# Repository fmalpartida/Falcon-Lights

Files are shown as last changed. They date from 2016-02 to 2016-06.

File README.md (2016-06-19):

# Falcon-Lights
Bandai 1:144 Millenium Falcon Light kit driver. 

This is a small board that retorfits into LED light compartment of the Bandai 1:144 Millenium Falcon kit.

The main difference between the original kit is its capability of driving upto to 6 white LEDs running from 2 AAAA batteries and fitting the whole assembly into the original compartment inside the Falcon.

## 3D Renders
Top

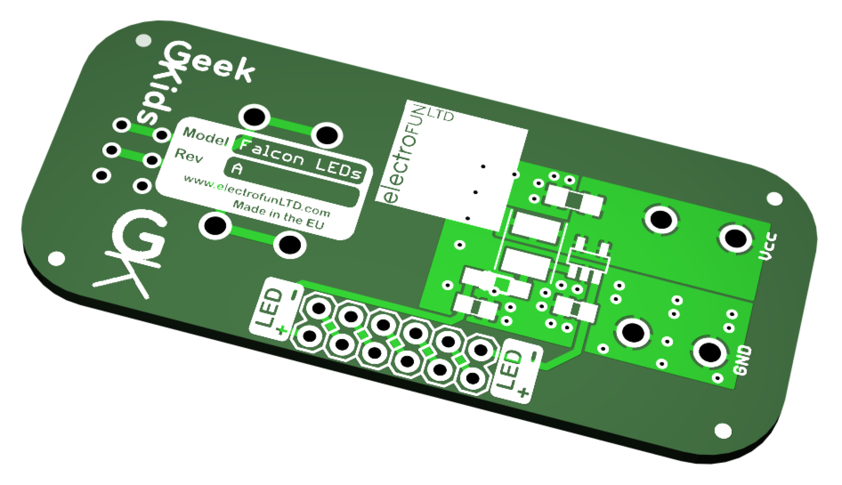
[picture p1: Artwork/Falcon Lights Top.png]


Bottom

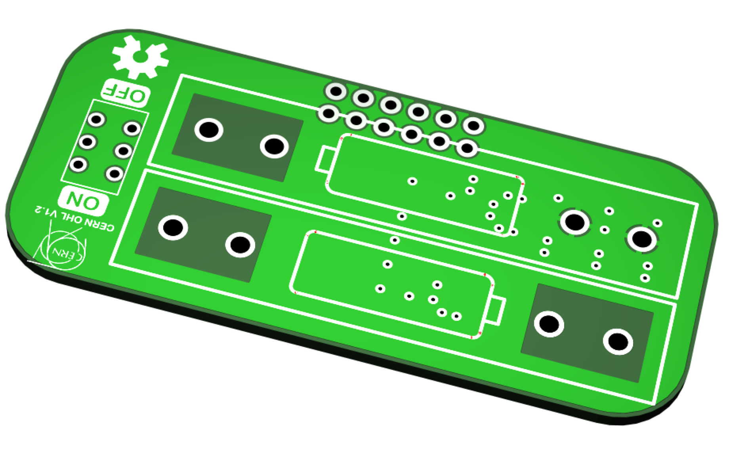
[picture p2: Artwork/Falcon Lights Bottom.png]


## Geek Kids Project
The board has been developed by electronFUN under the Geek Kids initiative. 

The Geek Kids initiative is a local electroFUN project where we try to bring youngsters close to technology. Kids under the initiative get exposed to technology projects while participating in them and bring up to speed for sharing with the general public. 

All the benefits derived from Geek Kids projects will revert back to the initiative and will help them develop more stuff and reachout to more kids.

All these projects are released under the Geek Kids logo and are Open Source for everyone to enjoy. 



Stay tunned.

## Where to get them
We don't have intentions to sell them and encourrage you to build them by yourself. If you would like us to build one for you please let me know by sending me a message, we will be delighted to build one for you.

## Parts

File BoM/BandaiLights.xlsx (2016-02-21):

Qty | Value | Device | Package | Parts | Description | Ref | Unit Price | TOTAL
6 |  | M02PTH | 1X02 | LED1, LED2, LED3, LED4, LED5, LED6 | Header 2 + LEDs |  | 0.0264 | 0.1584
1 | 1uF | C-EUC0805 | C0805 | C3 | CAPACITOR, European symbol | CC0805ZKY5V9BB105 | 0.053 | 0.053
1 | 10uF | C-EUC1206 | C1206 | C2 | CAPACITOR, European symbol | C1206C106Z8VACTU | 0.073 | 0.073
1 | 10uH-SRN3015-100M | WE-TPC_S | WE-TPC_S | L1 | Shielded Tiny Power Inductor WE-TPC | SRN3015-100M | 0.246 | 0.246
1 | 15R | R-EU_M0805 | M0805 | R1 | RESISTOR, European symbol | 667-ERJ-6ENF15R0V | 0.026 | 0.026
4 | AAAA-BATTERY | AAAA-BATTERY | 51-AAAA | U1, U2 |  | 534-51 | 0.238 | 0.952
1 | MBR0530L-TP | MBR0530LT | SOD123 | D1 | SCHOTTKY BARRIER RECTIFIER | MBR0530L-TP | 0.198 | 0.198
1 | FAN5333B | CAT4238 | SOT23-5 | Q1 | CAT4238 High efficiency 10 LED boost converter- ON Semi. | FAN5333B | 0.743 | 0.743
1 | JS202011CQN | MINI_SWITCH | SWITCH-JS202011 | S1 | Mini Switch ON-MON-OFF | JS202011CQN | 0.317 | 0.317
1 | PCB | FALCON LEDs |  |  | PCB fabrication |  | 4 | 4
6 | JST connectors |  |  |  |  |  | 0.4 | 2.4
 |  |  |  |  |  | TOTAL 10 u |  | 9.1664
 |  |  |  |  |  | VAT | 0.21 | 11.09

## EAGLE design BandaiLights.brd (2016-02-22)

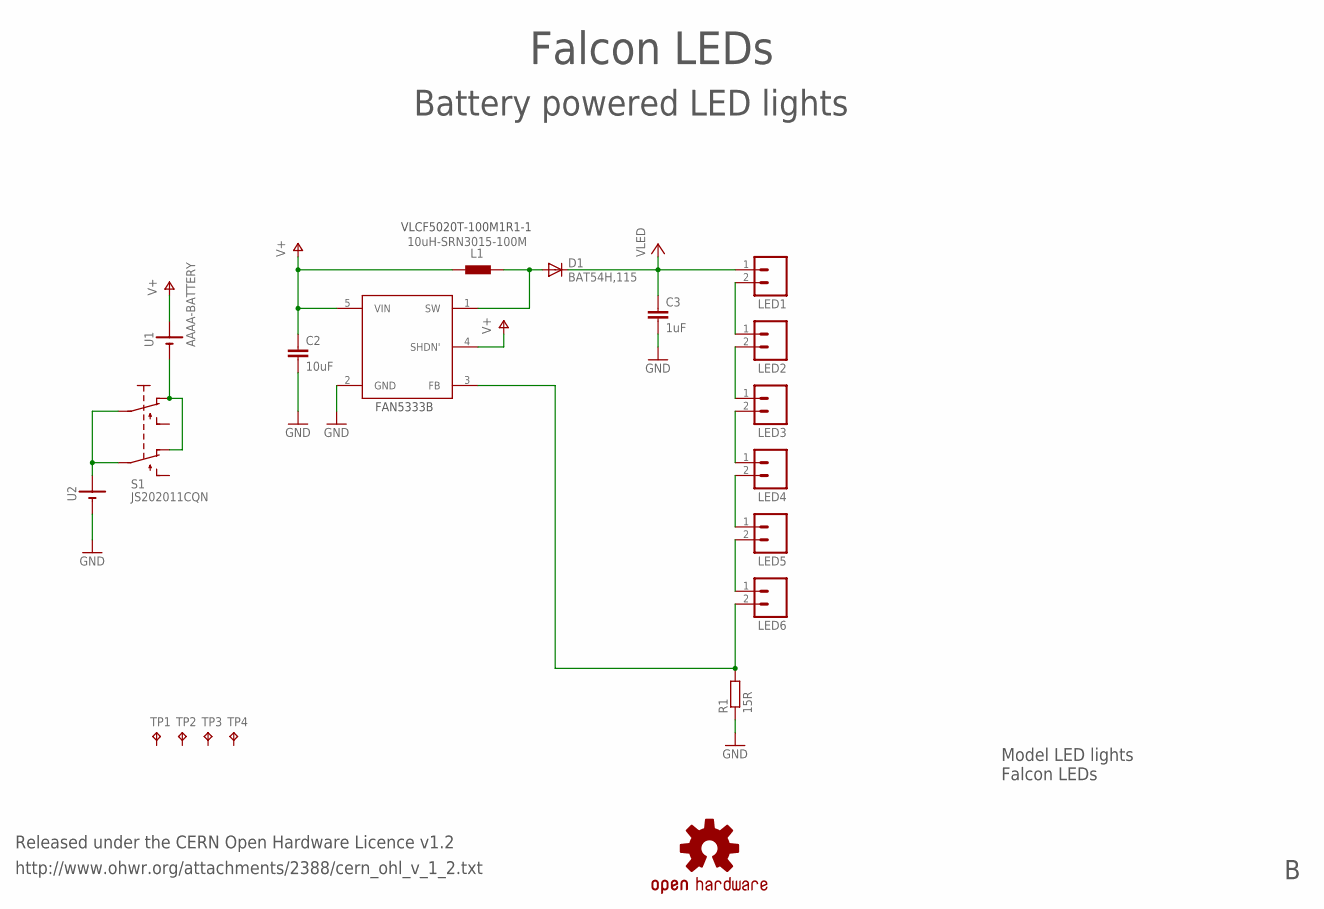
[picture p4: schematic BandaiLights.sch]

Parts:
C2: 10uF; C1206
C3: 1uF; C0805
D1: BAT54H,115; SOD123
L1: 10uH-SRN3015-100M; LQH
LED1, LED2, LED3, LED4, LED5, LED6: M02PTH; 1X02
Q1: FAN5333B; SOT23-5
R1: 15R; M0805
S1: JS202011CQN; SWITCH-JS202011
TP1, TP2, TP3, TP4: TPB1,27; B1,27
U1, U2: AAAA-BATTERY; 51-AAAA
U$4: SPARKFUN_OSHW-LOGOM; SPARKFUN_OSHW-LOGO-M

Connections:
FB: LED6.2, Q1.3 (FB), R1.2
GND: C2.2, C3.2, Q1.2 (GND), R1.1, U2.P3 (-), U2.P4 (-)
unnamed: LED1.2, LED2.1
unnamed: LED2.2, LED3.1
unnamed: LED3.2, LED4.1
unnamed: LED4.2, LED5.1
unnamed: D1.A, L1.2, Q1.1 (SW)
unnamed: LED5.2, LED6.1
unnamed: S1.P2, S1.P5 (P1), U2.P1 (+), U2.P2 (+)
unnamed: S1.P1 (O), S1.P4 (O1), U1.P3 (-), U1.P4 (-)
V+: C2.1, L1.1, Q1.4 (SHDN'), Q1.5 (VIN), U1.P1 (+), U1.P2 (+)
VCC: C3.1, D1.C, LED1.1

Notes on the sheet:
FAN5333B
Model LED lights Falcon LEDs
Battery powered LED lights
Released under the CERN Open Hardware Licence v1.2
http://www.ohwr.org/attachments/2388/cern_ohl_v_1_2.txt
VLCF5020T-100M1R1-1
Falcon LEDs

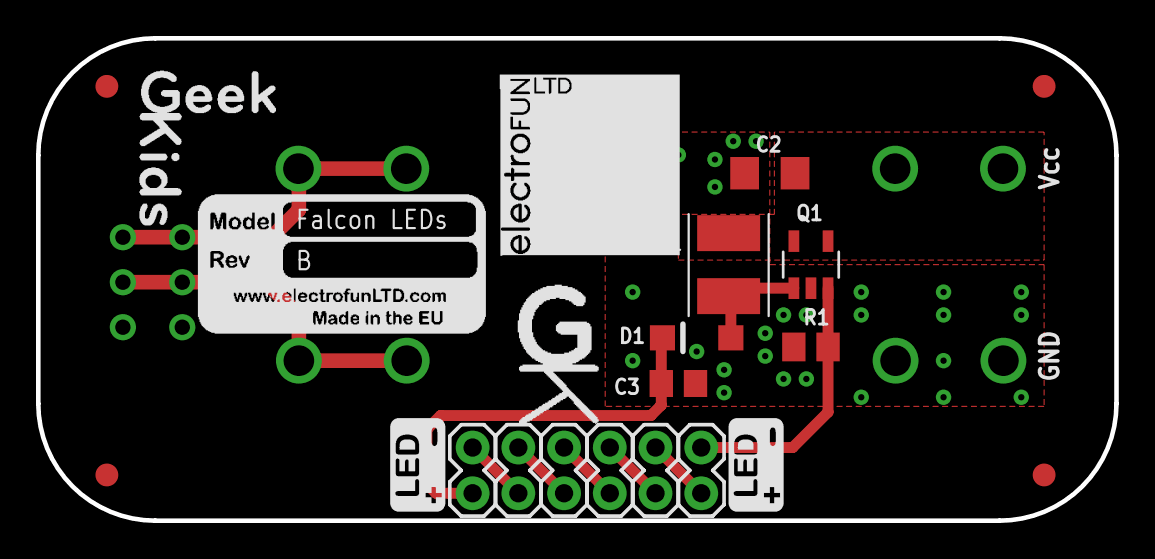
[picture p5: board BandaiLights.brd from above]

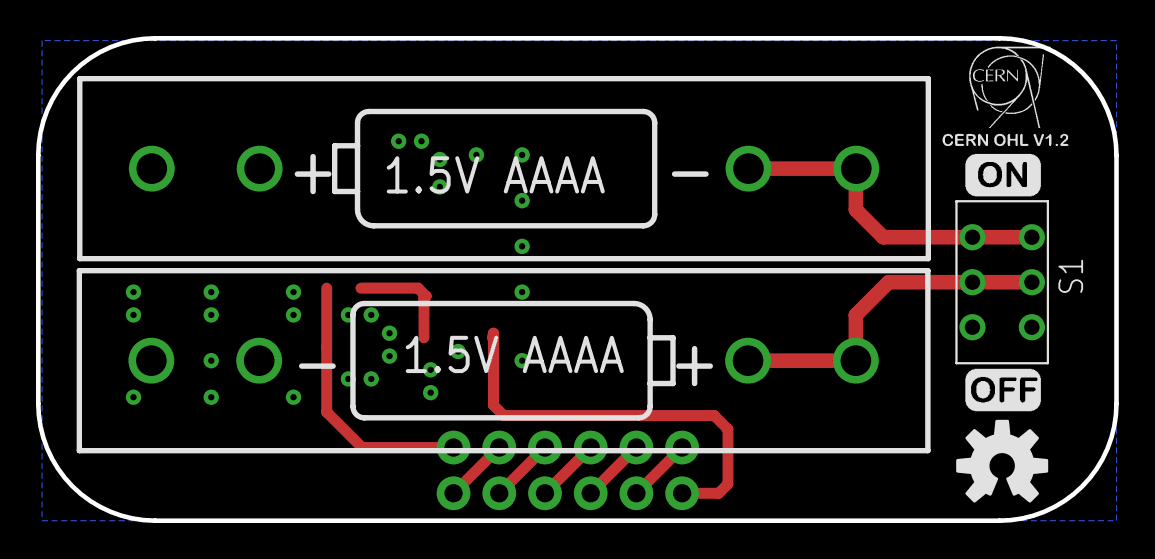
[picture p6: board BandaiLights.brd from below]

Board: 2 copper layers, 59.9 x 26.8 mm, 29 parts (7 on the bottom side), 12 nets.

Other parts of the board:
U$1: CERN_OHL
U$2: ON
U$3: ELECTROFUN_10X10
U$5: BOARD_INFO_BMP_SMALL
U$6: OFF
U$8, U$11: LED_SILK
U$9: GEEKKIDS_S
U$10: GEEKKIDS_LOGO_S

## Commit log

2016-02-21 PCB Revision A
    [BandaiLights.brd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]
2016-02-21 Revised PCB: - Revised LED layout to avoid having to rework the interior of the Falcon to fit all 6 LEDs - Revised silk screen to make it more readable. - Added GK (geek kids logo).
    Added license.
    [BandaiLights.brd, BandaiLights.sch]
2016-02-21 Updated PCB revision image in the project.
2016-02-22 Release Rev B, untested.
    [BandaiLights.brd, BandaiLights.sch]
2016-02-22 Removed gerbers till tested.
2016-06-19 Updated schematics.
    [BandaiLights.sch]

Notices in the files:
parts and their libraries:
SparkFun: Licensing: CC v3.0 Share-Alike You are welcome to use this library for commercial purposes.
